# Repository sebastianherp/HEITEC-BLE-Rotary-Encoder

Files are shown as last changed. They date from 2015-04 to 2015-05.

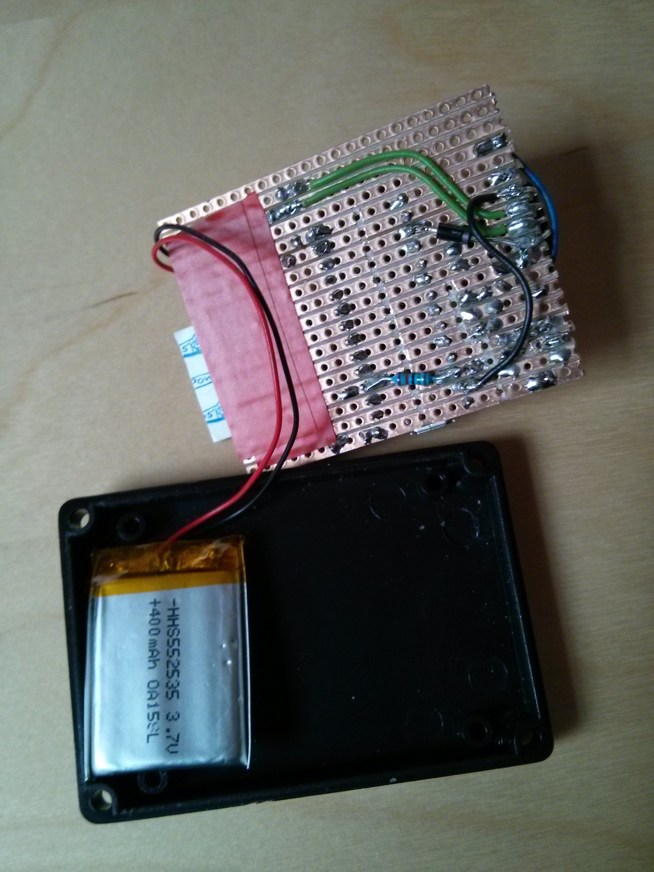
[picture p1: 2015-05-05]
Dokumentation/Encoder Bottom.jpg

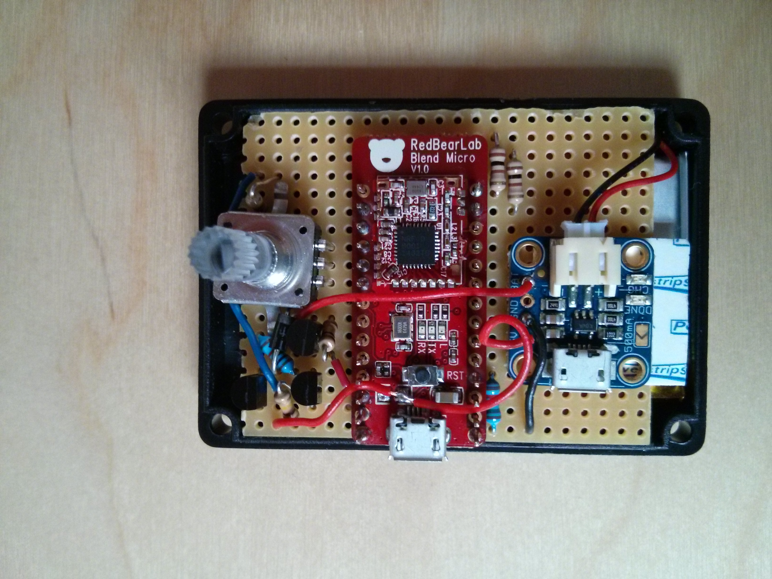
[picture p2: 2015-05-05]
Dokumentation/Encoder Top.jpg

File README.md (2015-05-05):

# BLE enabled Rotary Encoder with Pushbutton and 2 LEDs

Date: 5. Mai 2015

Author: Sebastian Herp

## Usage on Linux/Raspberry Pi (Bluez 5.30):

 - `hciconfig` => if it shows the interface to be down execute "sudo hciconfig hci0 up"
 - `sudo hcitool lescan` to scan for BLE devices
 - `gatttool -t random -b F0:0E:BD:D9:5B:3D --interactive` to start gatttool
 - `connect` => command line should change to blue and you should be connected to the Blend Micro with the address F0:0E:BD:D9:5B:3D
 - `char-write-req 0x0011 0100` asks for notifications opening the return channel (status messages, encoder position and button presses are received here)
 - `char-write-cmd 0x000e 00` asks for a status reply
 - `char-write-cmd 0x000e 01ff00` sets the red LED to full brightness (0100ff: green LED full brightness, 018080: both LEDs half brightness, 010000: both LEDs off)
 - `disconnect` / `exit` to disconnect from device

## Replies (hex values)

 - Status: "00 00 06 00 00 0d 75 20 00" (encoder pos = 00 06, leds = 00 00, voltage = 0d 75, bat. percentage = 20, running on USB power = 00)
 - Encoder movement: "01 00 10 01 5a" (encoder pos = 00 10, speed in deg/s = 01 5a)
 - Button: "02 01" (button pressed) and "02 00" (button depressed)

## Power saving strategy:

Since the Blend Micro always draws a minimum of 1.7-2.0 mA ( http://redbearlab.com/blend-low-power-settings/ ) a external
latching power switch is used. It is activated by USB power, button press and the Arduino Pin D5 being HIGH.

The Blend Micro deactivates itself after a long button press or the battery running below a certain voltage (default 3.4 V)
for some time (200 s) while not connected. It also deactivates below ~3.1 V because the gate voltage on the NPN transistor
will be to low.

While running power is saved by sleeping during periods of low activity. The Arduino wont sleep when connected to USB power,
a LED is on (PWM, not full brightness) and certain other conditions to make sure debounce, etc works. The LEDs will turn off
after a configurable amount of time (default 30 s) to save power.

## Power usage:

 - Off: 0.0 mA
 - Startup: 12-16 mA
 - Sleeping: ~2.5 mA (BLE still on in this mode)
 - Encoder movement or putton press: ~6.1 mA
 - LEDs:
    - red   = FE: 15 mA
    - green = FE: 10 mA
    - both  = FE: 17.4 mA
    - red   = FF: 11.9 mA
    - green = FF: 6.3 mA
    - both  = FF: 14.7 mA

## Development

### PC/Mac/Linux
 - Install Arduino 1.6.3+
 - Change the Skechtbook location to the Arduino directory of this repository
 - Done
 
### Raspberry Pi
 - Copy Raspbian Wheezy (2015-02-16) on a SD card (use Win32DiskImager on Windows)
 - Follow the instructions [here](http://www.elinux.org/RPi_Bluetooth_LE) to install Bluez 5.30 on Raspberry Pi
 - `gatttool`, `hciconfig` and `hcitool` should now be available on the command line

## References

 - http://redbearlab.com/blendmicro/
 - http://redbearlab.com/getting-started-blendmicro/
 - http://redbearlab.com/blend-low-power-settings/
 - http://www.arduino.cc/en/uploads/Main/arduino-leonardo-schematic_3b.pdf
 - https://github.com/RedBearLab/Blend/
 - https://github.com/RedBearLab/nRF8001
 - https://github.com/NordicSemiconductor/ble-sdk-arduino

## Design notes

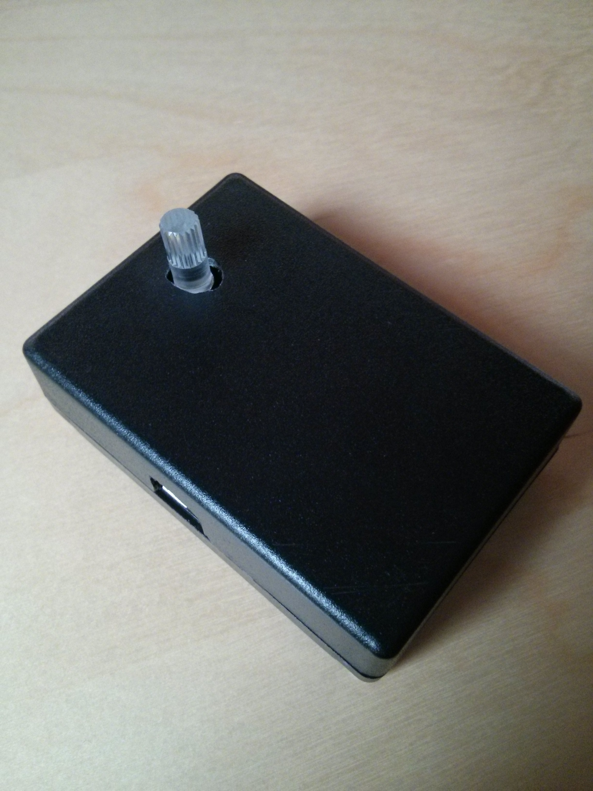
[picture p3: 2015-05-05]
Dokumentation/Encoder Case.jpg

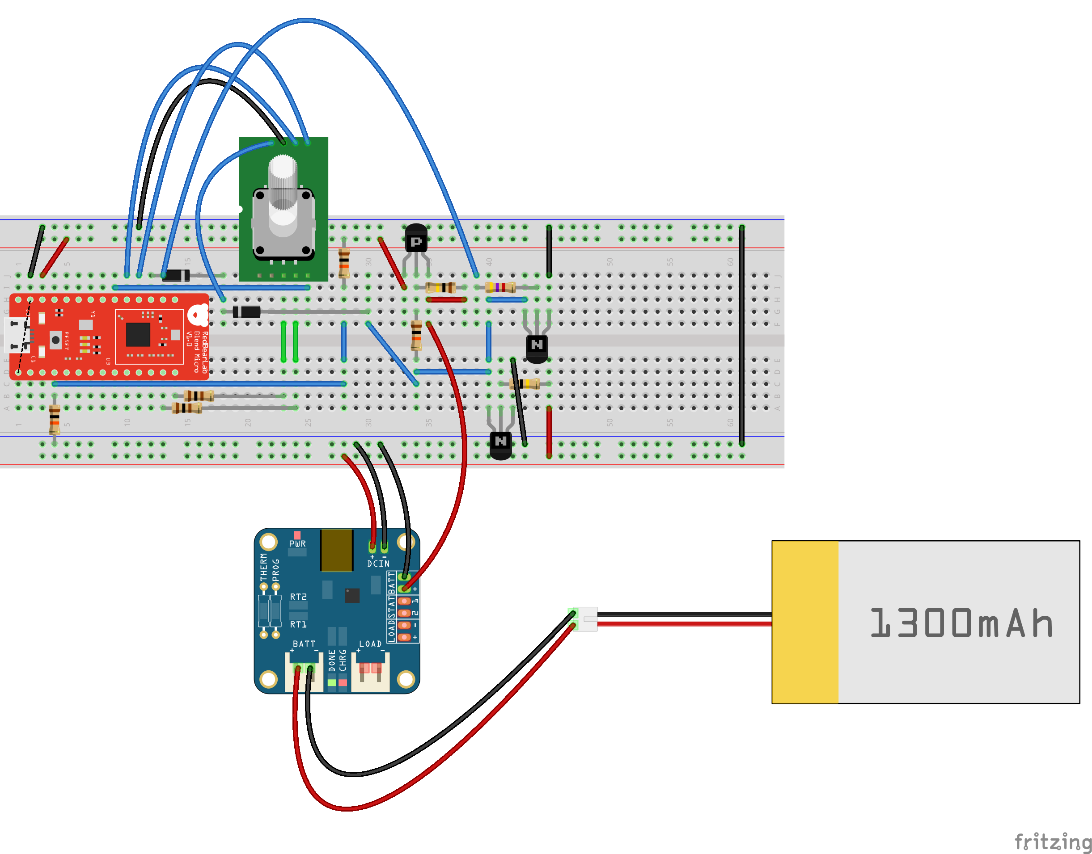
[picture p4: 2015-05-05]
Dokumentation/BLE Arduino Encoder with LEDs_Steckplatine.png

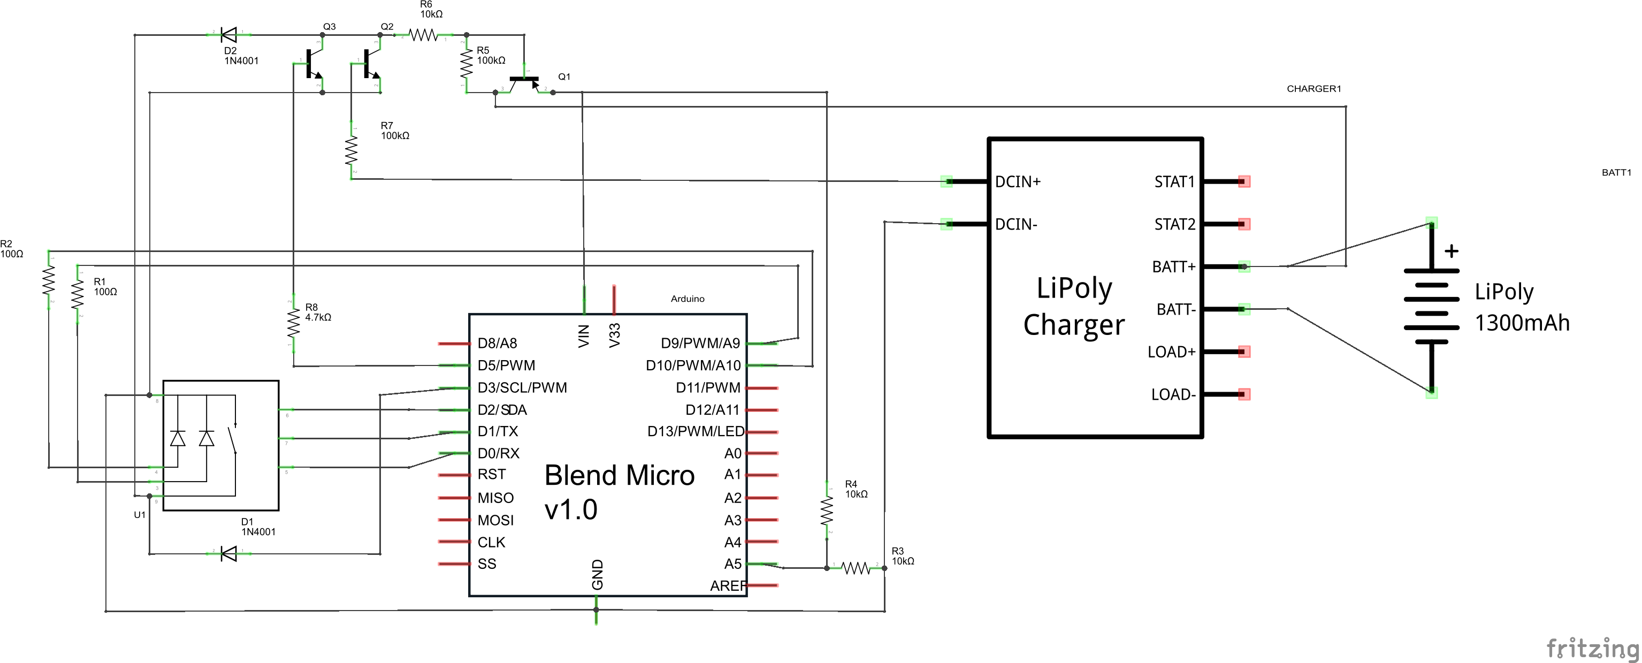
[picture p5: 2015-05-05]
Dokumentation/BLE Arduino Encoder with LEDs_Schaltplan.png

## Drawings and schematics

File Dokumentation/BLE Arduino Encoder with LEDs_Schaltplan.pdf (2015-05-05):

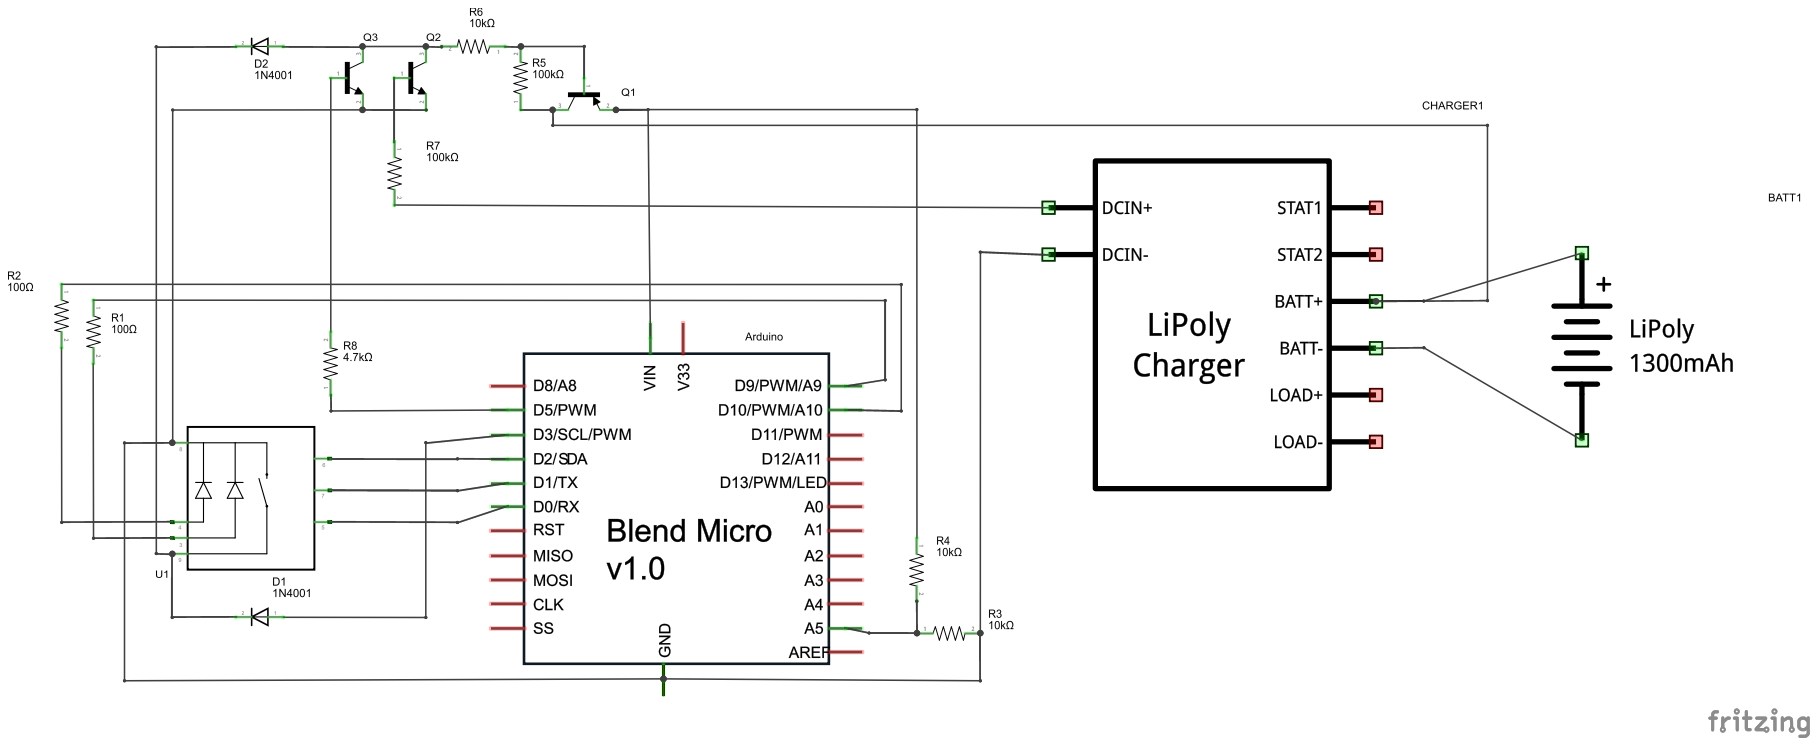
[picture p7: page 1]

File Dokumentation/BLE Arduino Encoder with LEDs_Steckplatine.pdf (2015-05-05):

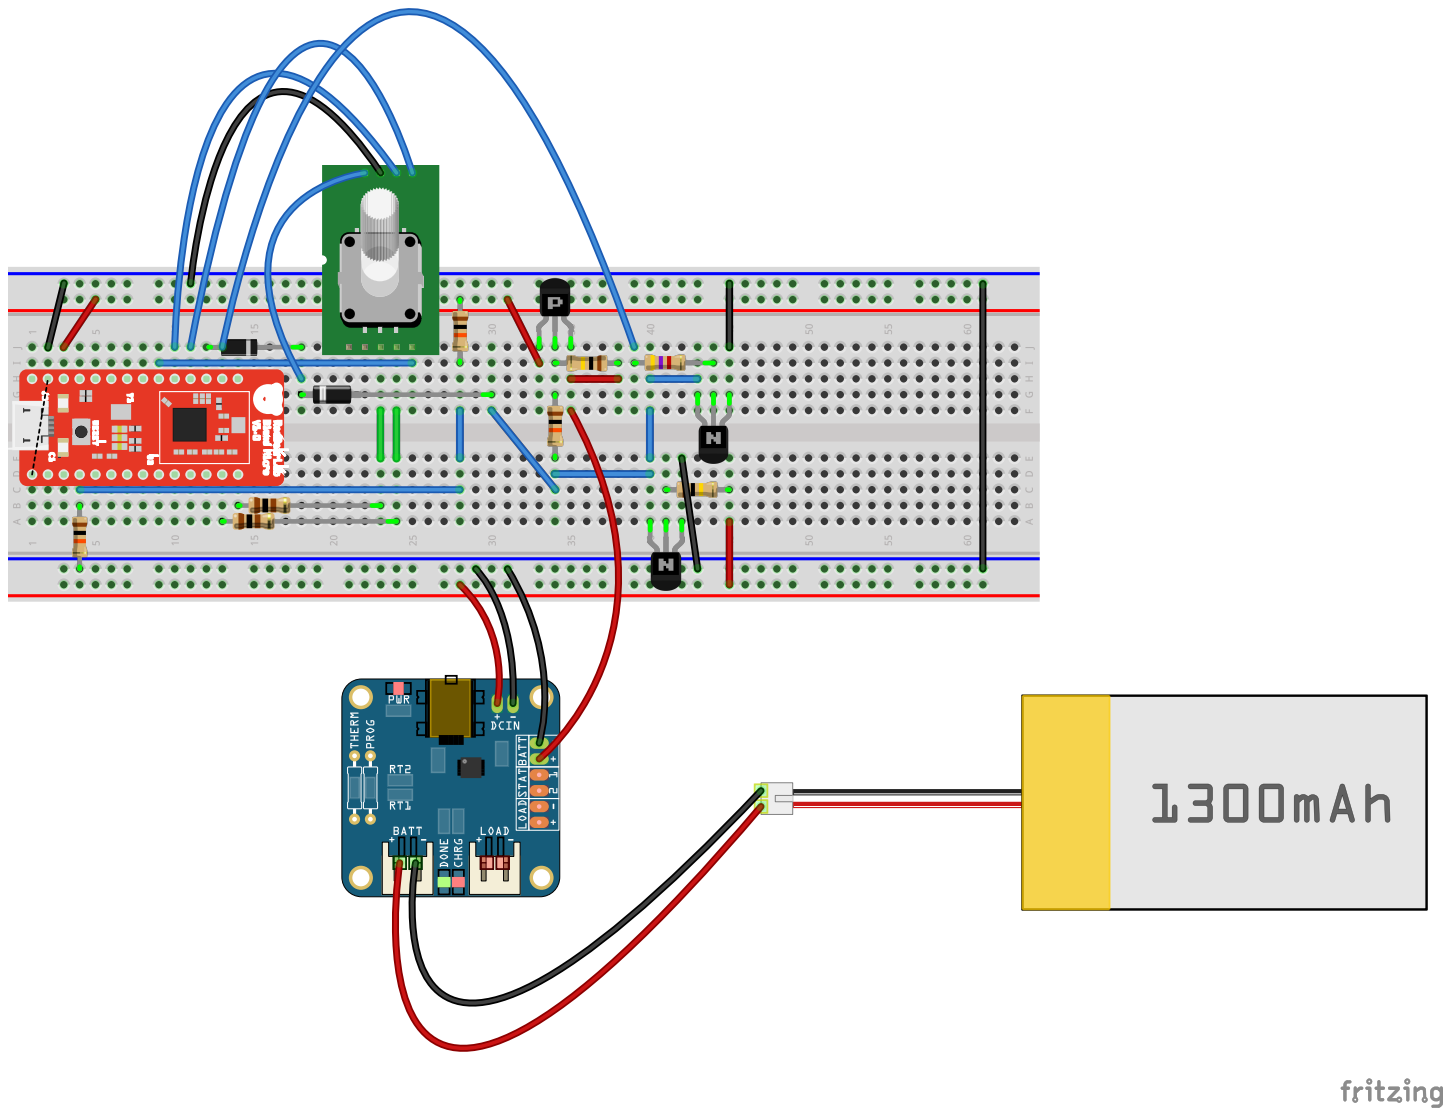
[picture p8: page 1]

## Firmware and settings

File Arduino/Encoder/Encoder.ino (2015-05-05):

/*******************************************************************
# BLE enabled Rotary Encoder with Pushbutton and 2 LEDs

Date: 5. Mai 2015

Author: Sebastian Herp

## Usage on Linux/Raspberry Pi (Bluez 5.30):

 - `hciconfig` => if it shows the interface to be down execute "sudo hciconfig hci0 up"
 - `sudo hcitool lescan` to scan for BLE devices
 - `gatttool -t random -b F0:0E:BD:D9:5B:3D --interactive` to start gatttool
 - `connect` => command line should change to blue and you should be connected to the Blend Micro with the address F0:0E:BD:D9:5B:3D
 - `char-write-req 0x0011 0100` asks for notifications opening the return channel (status messages, encoder position and button presses are received here)
 - `char-write-cmd 0x000e 00` asks for a status reply
 - `char-write-cmd 0x000e 01ff00` sets the red LED to full brightness (0100ff: green LED full brightness, 018080: both LEDs half brightness, 010000: both LEDs off)
 - `disconnect` / `exit` to disconnect from device

## Replies (hex values)

 - Status: "00 00 06 00 00 0d 75 20 00" (encoder pos = 00 06, leds = 00 00, voltage = 0d 75, bat. percentage = 20, running on USB power = 00)
 - Encoder movement: "01 00 10 01 5a" (encoder pos = 00 10, speed in deg/s = 01 5a)
 - Button: "02 01" (button pressed) and "02 00" (button depressed)

## Power saving strategy:

Since the Blend Micro always draws a minimum of 1.7-2.0 mA ( http://redbearlab.com/blend-low-power-settings/ ) a external latching power switch is used. It is activated
by USB power, button press and the Arduino Pin D5 being HIGH.

The Blend Micro deactivates itself after a long button press or the battery running below a certain voltage for some time while not connected. It also deactivates below
~3.1 V because the gate voltage on the NPN transistor will be to low.

While running power is saved by sleeping during periods of low activity. The Arduino wont sleep when connected to USB power, a LED is on (PWM, not full brightness) and
certain other conditions to make sure debounce, etc works. The LEDs will turn off after a configurable amount of time to save power.

## Power usage:

 - Off: 0.0 mA
 - Startup: 12-16 mA
 - Sleeping: ~2.5 mA (BLE still on in this mode)
 - Encoder movement or putton press: ~6.1 mA
 - LEDs:
    - red   = FE: 15 mA
    - green = FE: 10 mA
    - both  = FE: 17.4 mA
    - red   = FF: 11.9 mA
    - green = FF: 6.3 mA
    - both  = FF: 14.7 mA

*******************************************************************/

#include <SPI.h>
#include <EEPROM.h>
#include <boards.h>
#include <RBL_nRF8001.h>
#include <avr/power.h>
#include <avr/wdt.h>

// APPLICATION PARAMETERS
#define LED_AUTO_OFF 30000                         // in ms (LED turns off after this much time)
#define PUSHBUTTON_TURNOFF_MILLIS 5000             // in ms (hold the button this long to turn off the Arduino)
#define INTERVAL_STATUS_MESSAGES 0                 // in ms (0 to stop periodic sending)
#define INTERVAL_BATTERY_MEASUREMENTS 10000        // in ms 
#define LOW_BATTERY_VOLTAGE 3400                   // in mV (if voltage is below this value turn off Arduino when not in use)
#define ENCODER_THRESHOLD 7000                     // in µs (debounce)
#define PUSHBUTTON_THRESHOLD 250                   // in ms (debounce)
#define SERIAL_DEBUG 1                             // the BLE library has a lot of serial output, so commenting this doesn't really turn of UART messages

// PIN CONFIGURATION
#define PIN_POWER 5
#define PIN_BATTERY A5

#define PIN_LED_ARDUINO 13
#define PIN_LED_RED 10
#define PIN_LED_GREEN 9

#define PIN_PUSHBUTTON 3
#define PIN_PUSHBUTTON_BIT 0 // Arduino Pin 3 = PD0
#define PIN_ENCODER_GND 1
#define PIN_ENCODER_A 0      //
#define PIN_ENCODER_B 2      //
#define PIN_ENCODER_A_BIT 2  // Arduino Pin 0 = PD2
#define PIN_ENCODER_B_BIT 1  // Arduino Pin 2 = PD1
#define INT_ENCODER_A 2      // Arduino Pin 0 = Int 2
#define INT_ENCODER_B 1      // Arduino Pin 2 = Int 1
#define INT_PUSHBUTTON 0     // Arduino Pin 3 = Int 0

// VARIABLES
volatile uint32_t encAtime = 0, encBtime = 0, buttonTime = 0;
volatile uint8_t encAsignal = 0, encBsignal = 0, encAold = 0, encBold = 0;

volatile uint16_t halfSteps = 0;
volatile float halfStepsPerSecond = 0;
volatile float degreesPerSecond = 0;

volatile uint16_t encoderPos = 0;
volatile boolean buttonPressed = false;
volatile boolean buttonStateChanged = false;
uint32_t buttonPressedStartTime;

uint16_t batteryVoltage = 0;
uint8_t batteryPercentage = 100;
uint8_t batteryLowCounter = 0;

uint8_t brightnessRed = 0;
uint8_t brightnessGreen = 0;
uint32_t lastLEDchange = 0;

bool usbDetected = false;
volatile byte watchdogCounter;
extern volatile unsigned long timer0_millis;

ISR(WDT_vect) { increaseWatchdogCounter(); }

void increaseWatchdogCounter() {
  watchdogCounter++;
}

/***
Setup all used pins
*/
void setupPins() {
  // Ports
  pinMode(PIN_BATTERY, INPUT);
  
  pinMode(PIN_LED_ARDUINO, OUTPUT);
  pinMode(PIN_LED_RED, OUTPUT);
  pinMode(PIN_LED_GREEN, OUTPUT);
  
  pinMode(PIN_PUSHBUTTON, INPUT_PULLUP);
  pinMode(PIN_ENCODER_A, INPUT_PULLUP);
  pinMode(PIN_ENCODER_B, INPUT_PULLUP);
  pinMode(PIN_ENCODER_GND, OUTPUT);
  digitalWrite(PIN_ENCODER_GND, LOW);
}

/***
Setup() is the first routine the Arduino executes
*/
void setup() {
  // Make sure we have power
  pinMode(PIN_POWER, INPUT);
  digitalWrite(PIN_POWER, HIGH);
  
  // Pins
  setupPins();
  
  // For Blend Micro:
  //   Default pins set to 6 and 7 for REQN and RDYN
  //   So, no need to set for Blend Micro.
  //
  //ble_set_pins(3, 2);
  
  // Set your BLE advertising name here, max. length 10
  ble_set_name("Encoder");
  
  // Enable low power consumption (interrupt based communication)
  ble_low_power();
  
  // Init. and start BLE library.
  ble_begin();
  
  // Interrupts
  attachInterrupt(INT_ENCODER_A, intEncoderA, CHANGE);
  attachInterrupt(INT_ENCODER_B, intEncoderB, CHANGE);
  attachInterrupt(INT_PUSHBUTTON, intPushbutton, FALLING);
  
  // Initial measurement
  measureBattery(true);
  
#if defined(SERIAL_DEBUG)  
  // Debug output
  Serial.begin(115200); // baudrate doesn't matter => virtual usb com port
#endif

  // turn off internal LEDs
  TXLED1;
  RXLED1;	
  digitalWrite(PIN_LED_ARDUINO, LOW);
  
  // Detect USB connection
  USBCON = USBCON | B00010000;
  delay(700); 
  usbDetected = !(UDINT & B00000001);
  
  // blink ;-)
  uint8_t i,g;
  for(i=0;i<3;i++) {
    for(g=0;g<250;g+=2) {
      updateLEDs(0, g);
      delay(1);
    }
    for(g=250;g>0;g-=2) {
      updateLEDs(0, g);
      delay(1);
    }
    updateLEDs(0, 0);
  }
}

void loop() {
 
  handleEncoderEvent();
  
  handleButtonEvent();

  measureBattery();

  sendStatusMessage();
  
  handleRequest();

#if defined(SERIAL_DEBUG)
  //Serial.print("Loop: "); Serial.println(millis());
  //Serial.flush();
#endif  

  ble_do_events();

  if(lastLEDchange + LED_AUTO_OFF < millis()) {
    updateLEDs(0, 0);
  }
  
  // save power (normal: ~13 mA, sleep: 3 mA)
  // first sleep / powerdown turns off SPI, UART, I2C, etc ... normal power usage after the first sleep is ~6 mA)
  if(!usbDetected                        // don't sleep if running on USB power
    && ble_can_sleep()                   // only sleep when BLE chip has nothing to do
    && (brightnessRed == 0               // don't sleep if LEDs are PWMd
       || brightnessRed == 255)                
    && (brightnessGreen == 0
       || brightnessGreen == 255)
    && buttonPressed == false            // don't sleep while button is pressed
    && (micros() - encAtime > 2000000)   // encoder debounce 
    && (micros() - encBtime > 2000000)   // encoder debounce
    && (millis() - buttonTime > 2000)    // button debounce
    && millis() > 5000) {                // don't sleep in the first 5000 ms after startup

    // sleep for some time
    milliSleep(10000); //powerDown();
  }
}


void measureBattery() {
  measureBattery(false);
}

void measureBattery(boolean force) {
  static uint32_t lastMeasurement = 0;
  
  if(!force && lastMeasurement + INTERVAL_BATTERY_MEASUREMENTS > millis())
    return;
    
  // dump first read value
  analogRead(PIN_BATTERY);
    
  // voltage divider is 10k each, so voltage can be measured in a range of 0 - 6600 mV
  batteryVoltage = map(analogRead(PIN_BATTERY), 0, 1023, 0, 6600);
  batteryPercentage = constrain(map(batteryVoltage, 3300, 4100, 0, 100), 0, 100);
  
  // good enough?
  if(batteryVoltage > 3550)
    batteryPercentage = constrain(map(batteryVoltage, 3550, 4100, 50, 100), 50, 100);
  else if(batteryVoltage > 3400)  
    batteryPercentage = constrain(map(batteryVoltage, 3400, 3550, 25, 50), 25, 50);
  else
    batteryPercentage = constrain(map(batteryVoltage, 3150, 3400, 0, 25), 0, 25);
  
  if(batteryVoltage < LOW_BATTERY_VOLTAGE && !ble_connected()) { // 25% left (3,4V)
    batteryLowCounter++;
  } else {
    batteryLowCounter = 0;
  }
  
  // 20 times below 3,4 V (25%) and not connected => turn off Arduino to save power
  if(batteryLowCounter > 20 && !ble_connected()) {
    turnOff();
  }
  
  // if voltage falls below ~3,1 V Arduino turns off because the external "latched power switch" will turn off
}



void updateLEDs(uint8_t newRed, uint8_t newGreen) {
  if(brightnessRed != newRed || brightnessGreen != newGreen) {
    if(newRed == 255)
      digitalWrite(PIN_LED_RED, HIGH);
    else
      analogWrite(PIN_LED_RED, newRed);
      
    if(newGreen == 255)
      digitalWrite(PIN_LED_GREEN, HIGH);
    else
      analogWrite(PIN_LED_GREEN, newGreen);
      
    brightnessRed = newRed;
    brightnessGreen = newGreen;

#if defined(SERIAL_DEBUG)  
    Serial.print(F("LEDs changed, new values: red = ")); Serial.print(newRed);
    Serial.print(F(", green = ")); Serial.println(newGreen);
#endif
  }

  lastLEDchange = millis();
}

void sendStatusMessage() {
  sendStatusMessage(false);
}

void sendStatusMessage(boolean force) {
  static uint32_t lastStatus = 0;
  
  if( !force && 
      (INTERVAL_STATUS_MESSAGES <= 0 || lastStatus + INTERVAL_STATUS_MESSAGES > millis()) )
    return;
  
  measureBattery(true);
  
  // BLE output
    
  if( ble_connected() ) {
    ble_write(0x00);
    ble_write((uint8_t)(encoderPos >> 8));
    ble_write((uint8_t)(encoderPos & 0xFF));
    ble_write(brightnessRed);
    ble_write(brightnessGreen);
    ble_write((uint8_t)(batteryVoltage >> 8));
    ble_write((uint8_t)(batteryVoltage & 0xFF));
    ble_write(batteryPercentage);
    ble_write(usbDetected);
  }    
  
#if defined(SERIAL_DEBUG)  
  // Serial output
  Serial.print(F("Encoder position: ")); Serial.print(encoderPos);
  Serial.print(F(", LED (red): ")); Serial.print(brightnessRed);
  Serial.print(F(", LED (green): ")); Serial.print(brightnessGreen);
  Serial.print(F(", Battery: ")); Serial.print(batteryVoltage);
  Serial.print(F("mv (")); Serial.print(batteryPercentage);
  Serial.print(F("%), running on ")); Serial.println(usbDetected ? F("USB power") : F("battery"));
#endif

  lastStatus = millis();
}

/***

*/
void handleEncoderEvent() {
  static uint16_t lastReportedPos = 0;
  static boolean ledOn = false;
  
  if (lastReportedPos != encoderPos) {
    //digitalWrite(PIN_LED_ARDUINO, ledOn ? HIGH : LOW);
    ledOn = !ledOn;
    
    // BLE output
    if( ble_connected() ) {
      uint16_t temp = degreesPerSecond;
      ble_write(0x01);
      ble_write((uint8_t)(encoderPos >> 8));
      ble_write((uint8_t)(encoderPos & 0xFF));
      ble_write((uint8_t)(temp >> 8));
      ble_write((uint8_t)(temp & 0xFF));
    }

#if defined(SERIAL_DEBUG)    
    // Serial output
    Serial.print(F("Encoder position: ")); Serial.print(encoderPos);
    Serial.print(", Speed: "); Serial.print(degreesPerSecond);
    Serial.println(" deg/s");
#endif    
    lastReportedPos = encoderPos;
  }  
  
}


/***
Handle button changes and send them over to connected devices
*/
void handleButtonEvent() {
  if(buttonPressed) {

    // still pressed?
    if(!buttonStateChanged && digitalRead(PIN_PUSHBUTTON)) {
      buttonPressed = false;
      buttonStateChanged = true;
    }

    if(buttonStateChanged) {
      buttonStateChanged = false;

      // write down time the button was pressed
      if(buttonPressed)
        buttonPressedStartTime = millis();

      // BLE output
      if( ble_connected() ) {
        ble_write(0x02); // 0x02 = button
        ble_write(buttonPressed ? 0x01 : 0x00);
      }
      
      #if defined(SERIAL_DEBUG)
      // Serial output
      if(buttonPressed)
        Serial.println(F("Button press detected"));
      else {
        Serial.print(F("Button depress detected after "));
        Serial.print(millis() - buttonPressedStartTime);
        Serial.println(F("ms"));
      }
      #endif
      
      if(buttonPressed) {
        uint8_t tempRed = brightnessRed, tempGreen = brightnessGreen;
        updateLEDs(255, 0);
        delay(100);
        updateLEDs(0, 0);
        delay(50);
        updateLEDs(tempRed, tempGreen);
      }
    }  
    
    // turn off after enough time has passed
    if(buttonPressed) {
      if(millis() - buttonPressedStartTime > PUSHBUTTON_TURNOFF_MILLIS)
        turnOff();  
    }
    
  }
  

}

/***
Handle request made by a connect device:
0x00: send status message
0x01: turn on/off LEDs
*/
void handleRequest() {
  uint8_t tempRed, tempGreen;  
  
  if ( ble_available() )
  {
    uint8_t readVal;
    while ( ble_available() )
    {
      readVal = ble_read();
      switch(readVal) {
        case 0x00:
          sendStatusMessage(true);
          break;
        case 0x01:
          tempRed = ble_read();
          tempGreen = ble_read();
          updateLEDs(tempRed, tempGreen);
          break;
        default:
          break;
      }
    }
  }
  
}


/***
First encoder pin interrupt (where the counting happens)
*/
void intEncoderA(){
  PRR0 = 0x00;  // Power Reduction Register: open timer
  PRR1 = 0x00;

  uint32_t diff = micros() - encAtime;
  if( diff < ENCODER_THRESHOLD )
    return;

  encAold = encAsignal;
  encAsignal = bitRead(PIND, PIN_ENCODER_A_BIT);
  if( encAold == encAsignal )
    return;
    
  encAtime = micros();
  if( encAsignal == encBsignal )
    halfSteps--;
  else
    halfSteps++;
    
  encoderPos = halfSteps / 2;
  halfStepsPerSecond = (1000000.0 / diff) * 0.3 + halfStepsPerSecond * 0.7;
  degreesPerSecond = halfStepsPerSecond / 48 * 360;
}

/***
Second encoder pin interrupt
*/
void intEncoderB(){
  PRR0 = 0x00;  // Power Reduction Register: open timer
  PRR1 = 0x00;

  uint32_t diff = micros() - encBtime;
  if( diff < ENCODER_THRESHOLD )
    return;
    
  encBold = encBsignal;
  encBsignal = bitRead(PIND, PIN_ENCODER_B_BIT); //digitalRead(PIN_ENCODER_B); //
  if( encBold == encBsignal )
    return;
    
  encBtime = micros();
}

/***
Pushbutton interrupt handler
*/
void intPushbutton() {
  PRR0 = 0x00;  // Power Reduction Register: open timer
  PRR1 = 0x00;
    
  if( millis() - buttonTime < PUSHBUTTON_THRESHOLD )
    return;

  buttonPressed = true;
  buttonStateChanged = true;
  buttonTime = millis();  
}

/***
Turn off Arduino
*/
void turnOff() {
  #if defined(SERIAL_DEBUG)
  Serial.println(F("Turning off ..."));
  #endif
  for(uint8_t i=0;i<3;i++) {
    updateLEDs(255,0);
    delay(200);
    updateLEDs(0,255);
    delay(200);
  }
  updateLEDs(0,0);
  digitalWrite(PIN_POWER, LOW);  
}

/***
Init watchdog https://github.com/jcw/jeelib/blob/master/Ports.cpp
*/
void watchdogInterrupts (char mode) {
  // correct for the fact that WDP3 is *not* in bit position 3!
  if (mode & bit(3))
      mode ^= bit(3) | bit(WDP3);
  // pre-calculate the WDTCSR value, can't do it inside the timed sequence
  // we only generate interrupts, no reset
  byte wdtcsr = mode >= 0 ? bit(WDIE) | mode : 0;
  MCUSR &= ~(1<<WDRF);
  
  cli();
  
  #ifndef WDTCSR
  #define WDTCSR WDTCR
  #endif
  WDTCSR |= (1<<WDCE) | (1<<WDE); // timed sequence
  WDTCSR = wdtcsr;
  
  sei();
}


/***
Lose some time
from https://github.com/jcw/jeelib/blob/master/Ports.cpp
*/
void milliSleep(uint16_t milliseconds) {
  uint16_t timeleft = milliseconds;

  while(timeleft >= 16) {
    char wdp = 0; // wdp 0..9 corresponds to roughly 16..8192 ms
    // calc wdp as log2(msleft/16), i.e. loop & inc while next value is ok
    for (word m = timeleft; m >= 32; m >>= 1)
        if (++wdp >= 9)
            break;
    watchdogCounter = 0;
    watchdogInterrupts(wdp);
    powerDown();
    watchdogInterrupts(-1); // off
    // when interrupted, our best guess is that half the time has passed
    word halfms = 8 << wdp;
    timeleft -= halfms;
    if (watchdogCounter == 0) {
        break;
    }
    timeleft -= halfms;
  }
  
  // adjust millis counter
  timer0_millis += milliseconds - timeleft;
  
}

/***
Power down everything except interrupts and BLE
*/
void powerDown() {
  uint8_t tempADCSRA = ADCSRA;
  ADCSRA = 0;
  power_adc_disable();
  //ACSR |= (1 << ACD); // disable Analog comparator, saves 4 uA
  
  power_usart0_disable();
  //power_spi_disable(); /do that a bit later, after we power RFM12b down
  power_twi_disable();
  power_timer0_disable(); // Do not disable if you need millis()!!!
  power_timer1_disable();
  power_timer3_disable();
  PRR1 |= (uint8_t)(1 << 4); //PRTIM4
  power_usart1_disable();
  
  // Switch to RC Clock 
  UDINT &= ~(1 << SUSPI); // UDINT.SUSPI = 0; Usb_ack_suspend
  USBCON |= ( 1 <<FRZCLK); // USBCON.FRZCLK = 1; Usb_freeze_clock
  PLLCSR &= ~(1 << PLLE); // PLLCSR.PLLE = 0; Disable_pll
  CLKSEL0 |= (1 << RCE); // CLKSEL0.RCE = 1; Enable_RC_clock()
  while ( (CLKSTA & (1 << RCON)) == 0){} // while (CLKSTA.RCON != 1); while (!RC_clock_ready())
  CLKSEL0 &= ~(1 << CLKS); // CLKSEL0.CLKS = 0; Select_RC_clock()
  CLKSEL0 &= ~(1 << EXTE); // CLKSEL0.EXTE = 0; Disable_external_clock
  
  // Datasheet says that to power off the USB interface we have to: 
  // Detach USB interface 
  // Disable USB interface 
  // Disable PLL 
  // Disable USB pad regulator 
 
  // Disable the USB interface 
  USBCON &= ~(1 << USBE); 
  
  // Disable the VBUS transition enable bit 
  USBCON &= ~(1 << VBUSTE); 
  
  // Disable the VUSB pad 
  USBCON &= ~(1 << OTGPADE); 
  
  // Freeze the USB clock 
  USBCON &= ~(1 << FRZCLK); 
  
  // Disable USB pad regulator 
  UHWCON &= ~(1 << UVREGE); 
  
  // Clear the IVBUS Transition Interrupt flag 
  USBINT &= ~(1 << VBUSTI); 
  
  // Physically detact USB (by disconnecting internal pull-ups on D+ and D-) 
  UDCON |= (1 << DETACH); 
  
  power_usb_disable(); // Keep it here, after the USB power down  
  
  //ble_sleep();
  //delay(50);
  power_spi_disable();
  
  
  // turn off LEDs
  TXLED1;
  RXLED1;	
  digitalWrite(PIN_LED_ARDUINO, LOW);
  
  pinMode(PIN_BATTERY, INPUT_PULLUP);

  set_sleep_mode(SLEEP_MODE_PWR_DOWN);
  cli();
  sleep_enable();
#ifdef BODSE
  MCUCR = MCUCR | bit(BODSE) | bit(BODS); // timed sequence
  MCUCR = (MCUCR & ~ bit(BODSE)) | bit(BODS);
#endif 
  sei();
  
  sleep_cpu();

  // Arduino sleeps

  sleep_disable();

  // wake up
  setupPins();
  
  // turn on ADC
  power_adc_enable();
  ADCSRA = tempADCSRA;
  
}

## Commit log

2015-04-30 Test: Stromverbrauch => 1,655 mA min mit powerDown() Funktion
2015-05-05 Schaltplan, Steckplatine generiert mit Fritzing
    [BLE Arduino Encoder with LEDs.fzz]
2015-05-05 Dokumentation und kleine Änderung um mehr Strom zu sparen
2015-05-05 Copy docs from Readme to Arduino ino file
